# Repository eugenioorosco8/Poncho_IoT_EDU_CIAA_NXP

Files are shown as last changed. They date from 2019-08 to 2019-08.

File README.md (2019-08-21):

# Poncho_IoT_EDU_CIAA_NXP
El proyecto argentino CIAA, con alcance latinoamericano, lleva adelante el desarrollo y producción de sistemas embebidos, con fines educativos, industriales y científicos. El presente es un sistema embebido integral basado en la versión EDU-CIAA NXP, con fines educativos y de investigación aplicada. Se desarrolla el Hardware y el Software requeridos con el fin de proporcionar un circuito impreso de expansión de “Internet de las cosas” (IoT), capaz de brindar múltiples tecnologías como son: Wifi, Bluetooth, GSM, portabilidad SD, y RF. El desarrollo posee dos partes principales. La primera, basada en un microcontrolador ATMEL, consiste en la utilización de nodos provistos de sensores y módulos de comunicación. En la segunda parte, se diseña un nodo central de gran capacidad de procesamiento. La plataforma de desarrollo Nacional EDU-CIAA NXP, en conjunto con la placa de expansión IoT diseñada se emplea en la segunda etapa.

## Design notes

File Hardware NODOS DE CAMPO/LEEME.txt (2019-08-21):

En esta carpeta se encuentran los archivos de KiCAD del PCB del nodo.
En la carpeta componentes_nodo.pretty se encuentran los componentes electrronicos creados para el nodo, ya que se recomienda crear nosotros mismos los componentes que vamos a utilizar (creacion de librerias).
Las carpetas socket son plantillas que incluyen los terminales del arduino Nano. estas plantillas se pueden obtener desde GitHub, al igual que plantillas de otras plataformas.

NODO.sch--> Esquematico del diseño
NODO.pcb--> PCB del proyecto (pistas)
los demas archivos son empleados por los dos anteriores.

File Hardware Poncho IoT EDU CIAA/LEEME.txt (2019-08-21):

En este directorio se encuentran todos los archivos necesario para editar el poncho de la EDU CIAA
-->PCB para imprimir : se encuentran todos los archivos pdf para realizar el circuito PCB
-->lib : Se encuentran todos los mudulos creados , ordenados por Carpeta
-->basico.pcb :archivo KiCAD del circuito PCB
-->basico.sch : archivo KiCad con diagrama esquematico

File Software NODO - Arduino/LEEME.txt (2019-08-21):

Se adjunta el codigo arduino para el funcionamiento de los nodos. El nodo 1 y 2 tienen variantes entre si, las mismas se encuentras comentadas en el codigo arduino.
Se incluyen todas las librerias requeridas para el proyecto.

Julian Juan Manuel Mayo 2019

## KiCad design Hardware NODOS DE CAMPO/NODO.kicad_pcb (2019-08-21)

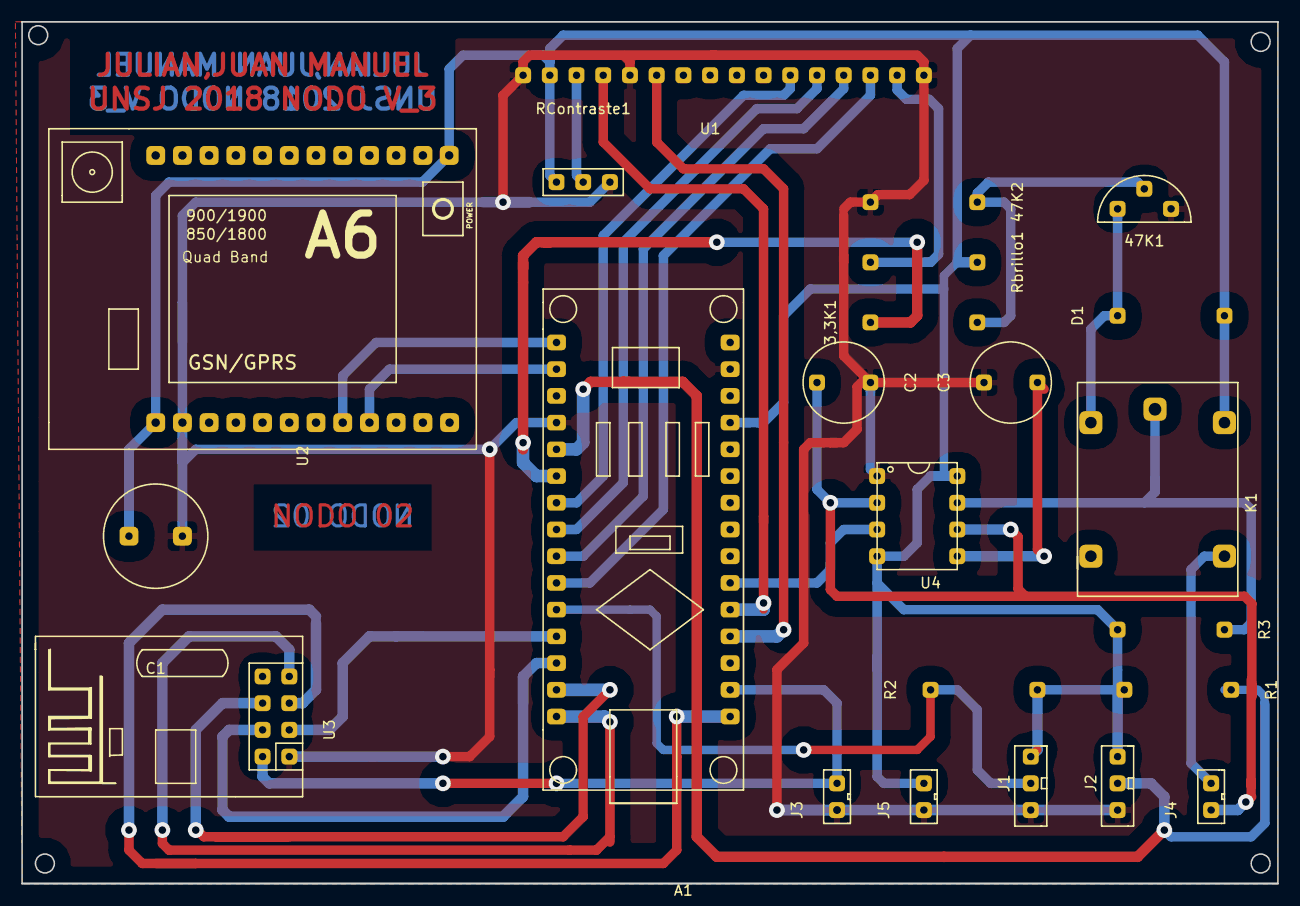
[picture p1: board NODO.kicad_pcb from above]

Board: 2 copper layers, 119.4 x 81.9 mm, 23 parts (0 on the bottom side), 28 nets.

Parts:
3,3K1: R1; Resistencia
47K1: BC337; Transisitor_BC337
47K2: R2; Resistencia
A1: Arduino_Nano_v3.x; Arduino_nano
C1: CP; Capacitor_GSM
C2: 0.1; capacitor
C3: CP; capacitor
D1: 1N4007; Resistencia
J1: Temp Suelo; connectorx3
J2: DHT22; connectorx3
J3: C 3.3V; connectorx2
J4: Sensor_HumedadS; connectorx2
J5: C 5V; connectorx2
K1: G5Q-1; rele
R1, R2: 10K; Resistencia
R3: 1K; Resistencia
RContraste1: 10K; potenciometro_presicion
Rbrillo1: R; Resistencia
U1: lcd_1602
U2: A6_GSM
U3: NRF24L01_Breakout; modulo_rf
U4: LM555

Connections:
/3.3V: A1.17, J3.1, U3.2
/5V: A1.27, C1.1, D1.1, J1.1, J2.1, J5.1, K1.5, R1.1, R2.1, R3.1, RContraste1.3, Rbrillo1.2, U1.2, U2.1, U2.24, U4.4, U4.8
/13(SCK): A1.16, U3.5
/+_SHUM: K1.2, R3.2, U4.7
/D2: A1.5, J2.2, R1.2
/D3: 3,3K1.2, A1.6
/D4: A1.7, U1.11
/D5: A1.8, U1.12
/D6: A1.9, U1.13
/D7: A1.10, U1.14
/D8: A1.11, J1.2, R2.2
/D9: A1.12, U3.3
/D10: A1.13, U3.4
/D11(MOSI): A1.14, U3.6
/D12(MISO): A1.15, U3.7
/POT_M: RContraste1.2, U1.3
/RX: A1.1, U2.8
/R_LIGHT: Rbrillo1.1, U1.15
/S_HUM+: J4.1, K1.3
/S_HUM-: C2.1, J4.2, U4.2, U4.6
/S_Hum: A1.21, U4.3
/TX: A1.2, U2.9
GND: 47K1.3, 47K2.1, A1.4, A1.29, C1.2, C2.2, C3.2, J1.3, J2.3, J3.2, J5.2, RContraste1.1, U1.1, U1.5, U1.16, U2.2, U3.1, U4.1
unnamed: 3,3K1.1, 47K1.2, 47K2.2
unnamed: 47K1.1, D1.2, K1.1
unnamed: A1.19, U1.6
unnamed: A1.20, U1.4
unnamed: C3.1, U4.5

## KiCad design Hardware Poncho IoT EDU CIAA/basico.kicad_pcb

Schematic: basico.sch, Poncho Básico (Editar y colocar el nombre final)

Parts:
C1: CP; CP_Radial_D10.0mm_P5.00mm
RV1: R_POT_US
U1: NRF24L01_Breakout; nRF24L01_Breakout
U2: ESP8266_CIAA
U3: HC05
U4: SD_card_CIAA
U5: A6_GSM; A6_gsm
U6: lcd_1602
XA101: Conn_Poncho2P_2x_20x2; Conn_Poncho_SinBorde; Digikey# 952-1387-ND

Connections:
+3.3VP: U1.2, XA101.41 (+3.3V)
+3V3: U2.6, XA101.1 (+3.3V)
+5V: C1.1, RV1.1, U3.5, U4.2, U5.1, U6.1, U6.15, XA101.2 (+5V), XA101.42 (+5V)
/CE: U1.3, XA101.78 (GPIO7)
/CS: U4.6, XA101.74 (GPIO3)
/CSN: U1.4, XA101.69 (GPIO0)
/D4: U6.11, XA101.70 (lcd1)
/D5: U6.12, XA101.68 (lcd2)
/D6: U6.13, XA101.66 (lcd3)
/D7: U6.14, XA101.62 (lcd4)
/E: U6.6, XA101.63 (lcdEN)
/IRQ: U1.8, XA101.76 (GPIO5)
/MISO: U1.7, U4.3, XA101.58 (spiMISO)
/MOSI: U1.6, U4.4, XA101.61 (spiMOSI)
/PWR_A6: U5.24, XA101.80 (GPIO8)
/RS: U6.4, XA101.64 (lcdRS)
/SCK: U1.5, U4.5, XA101.60 (spiSCK)
/UART0_RX: U5.8, XA101.71 (GPIO2)
/UART0_TX: U5.9, XA101.72 (GPIO1)
/UART2_RX: U3.3, XA101.50 (ethCRS)
/UART2_TX: U3.2, XA101.49 (ethRXD0)
/UART3_RX: U2.5, XA101.23 (rs232RXD)
/UART3_TX: U2.4, XA101.25 (rs232TXD)
GND: C1.2, RV1.3, U1.1, U2.1, U3.4, U4.1, U5.2, U5.23, U6.2, U6.5, U6.7, U6.8, U6.9, U6.10, U6.16, XA101.4 (GND), XA101.40 (GND), XA101.43 (GND)
unnamed: RV1.2, U6.3

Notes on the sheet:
UART0
UART2
UART3
WI-FI
BLUETOOTH
GPRS
SD_CARD
SPI

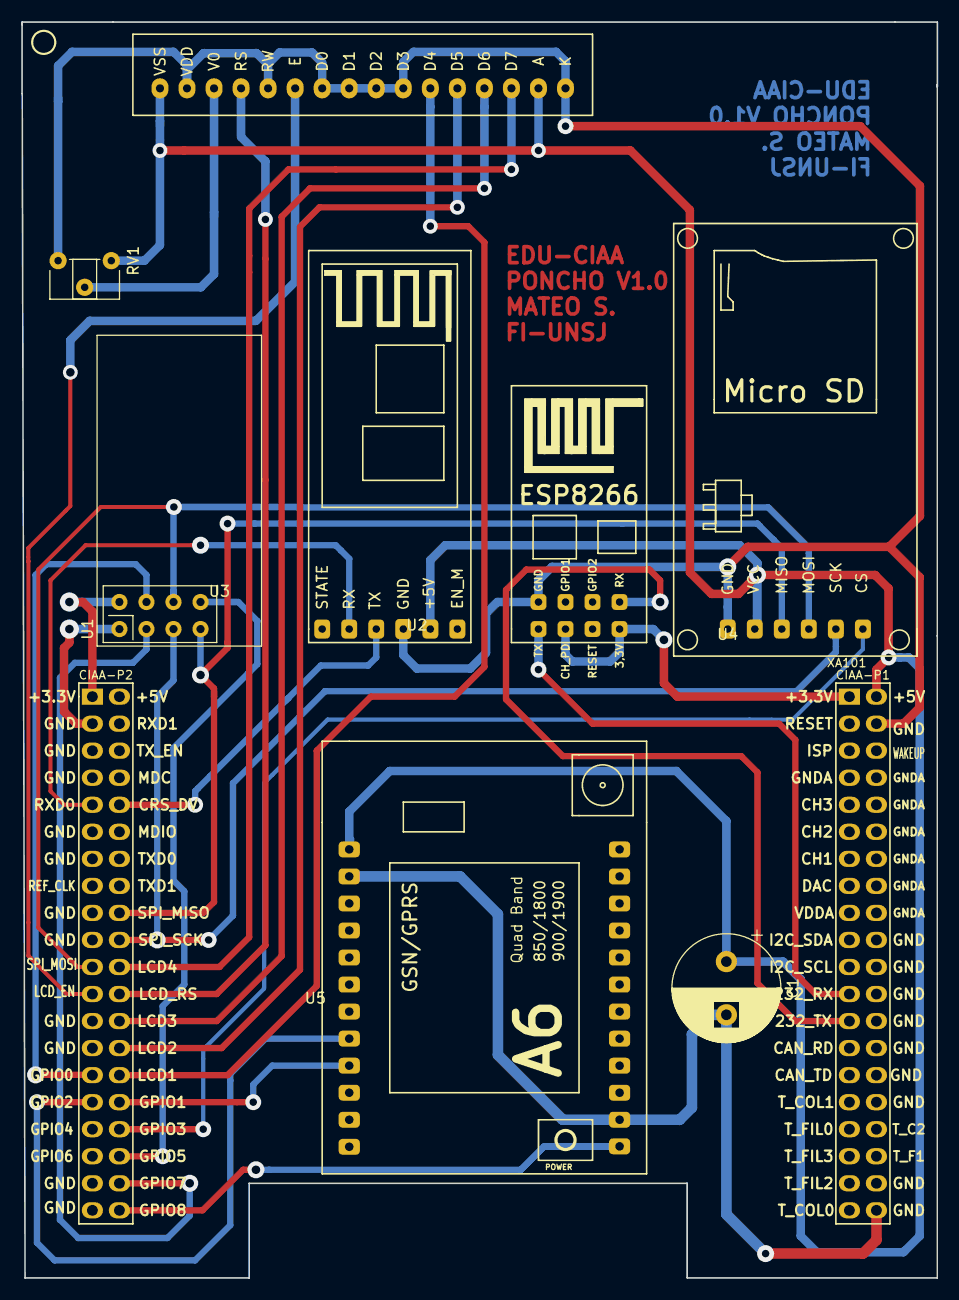
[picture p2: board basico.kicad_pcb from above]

Board: 2 copper layers, 86.0 x 118.0 mm, 9 parts (0 on the bottom side), 25 nets.

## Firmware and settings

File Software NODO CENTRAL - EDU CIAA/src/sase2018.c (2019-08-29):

/*
===============================================================================
 /*
===============================================================================
 Name        : test.c
 Author      :JULIAN BY MATEO
 Version     :
 Copyright   : $(copyright)
 Description : main definition
===============================================================================
*/

#if defined (__USE_LPCOPEN)
#if defined(NO_BOARD_LIB)
#include "chip.h"
#else
#include "board.h"
#endif
#endif

#include <cr_section_macros.h>
//---------------------- INCLUDES PROJECT SD-----------------------------

#include <chip.h>
#include "ff.h"
#include <diskio.h>
#include "WorkSD.h"
#include "rtc.h"
#include <string.h>
#include <stdlib.h>
#include "WorkApp.h"
// LCD
#include "puertos.h"
#include "lcd.h"
// ESP8266
#include "Serial.h"
#include "ESP8266.h"


//--------------------- ESP8266 ------------------------------------------
#define Intentos 2
#define Tiempo_Espera 7 // equivale a 14 seg
#define ssid "wifi-2"
#define password "tplinkmateo15"
unsigned char flag_WiFi=0, flag_GPRS=0, time_out=0, busy=0,pipe;

//**********************************************************************************************************
//                     Interrupcion del RIT Timer
//**********************************************************************************************************

 void RIT_IRQHandler(void){
	 uint16_t static contador=0;
	 if(contador < 15){ contador ++;}
	 else{ contador=0;  }

     time_out++;
     Chip_RIT_ClearInt(LPC_RITIMER);
     NVIC_ClearPendingIRQ(RITIMER_IRQn);
}



//---------------------INCLUDES PROJECT RF--------------------------------

	#include "UPC_nRF24L01.h"

	uint8_t pipe_00[5] = {"PIPE0"};
	uint8_t pipe_01[5] = {"PIPE1"};
    unsigned char mensaje[8] = {1,2,4,8,16,32,64,128};
    #define  nameWidth 3
	#define FCH 90
	#define dataRate 0 // 0-> 1Mbps  ,   1-> 2Mbps
	#define PowerOut 3 //0=> -18dBm, 1 => -12dBm, 2 => -6dBm, 3 => 0dBm
	#define EnableChecksum 0 // 0->Disable , 1 -> Enable
	#define PAYLOAD 8  // NUMEROS DE BYTES A ENVIAR
    #define LNA_Gain 1 //  0 => Disabled, 1 => Enabled
	#define CRC_Setup 2 //0 => 1byte, 1 => 2byte
    #define Mascara_Pipe 0b00001110


//-------------------------INCLUDE PROJECT BLUETOOTH--------------------------

#include  "Work_Bluetooth.h"

 //------------------------INCLUDE ADC TANQUE---------------------------------

#include "Work_ADC.h"

//------------------------------INCLUDE BOMBA--------------------------------

#include <Work_Bomba.h>

//---------------------------------INCLUDE CALENTADOR PID---------------------
#include "TriAc.h"
#define KI 0.03
#define KP 2
#define Tolerancia 2
#define Zona_Muerta 5
#define Ts 5

//-----------------------------VARIABLES GLOBALES------------------------------
    // Datos Pipe 0
    int Datos_SD[5]={0};	//Datos provenientes del Nodo 0
    char RX_Payload[8]={0};
    //Datos Pipe 1
    int Datos_SD_01 [5]={0};	//Datos provenientes del Nodo 1
    char RX_Payload_01[8]={0};

    int Ref_Temp_App=25;	//Dato de referencia primera pasada temperatura




//-------------------------INTERRUPT RIT----------------------------------------

  /*  void RIT_IRQHandler(void){
    static int Mediciones[4]={173,128,589,123}; //mediciones x10 (a una cifra decimal) samuel

    		/*Write_MeasurementsSD(Mediciones);
    		Last_Values_App(Mediciones);

    		Chip_RIT_ClearInt(LPC_RITIMER);
    		NVIC_ClearPendingIRQ(RITIMER_IRQn);


    }*/


//--------------------------------------MAIN------------------------------------

    //*************************************** lcd *********************************
    /*

*/

int main(void) {


#if defined (__USE_LPCOPEN)
    // Read clock settings and update SystemCoreClock variable

	SystemCoreClockUpdate();
#if !defined(NO_BOARD_LIB)
#if defined (__MULTICORE_MASTER) || defined (__MULTICORE_NONE)
    // Set up and initialize all required blocks and
    // functions related to the board hardware
    Board_Init();
#endif
    // Set the LED to the state of "On"
    Board_LED_Set(0, true);
#endif
#endif
// Force the counter to be placed into memory
volatile static int i = 0 ;
// Enter an infinite loop, just incrementing a counter

//******************************************* LCD  *********************************************************
    lcd_init_port();
    lcd_init();

    lcd_gotoxy(1, 1);
    printf_lcd("   TESIS 2019 ");
    lcd_gotoxy(1, 2);
    printf_lcd(" JULIAN - MATEO ");

//**************************************************************************
//**************** RITIMER**************************************************
//**************************************************************************
    /*
     Chip_RIT_Init(LPC_RITIMER);
     Chip_RIT_SetTimerInterval(LPC_RITIMER,2000);
     Chip_RIT_Enable(LPC_RITIMER);
     NVIC_EnableIRQ(RITIMER_IRQn);
*/
     uint8_t static caso=0,estado=0,cont_fail=0;

//***************************************************************************
//                  PIN POWER A6
//***************************************************************************
     Chip_SCU_PinMux (6,12,MD_PUP,FUNC3); // CS
     Chip_GPIO_SetPinDIROutput(LPC_GPIO_PORT,2, 8);
     Chip_GPIO_SetPinOutHigh(LPC_GPIO_PORT,2,8);

//----------------------------------------REGITRO HORARIO PARA SD ARCHIVOS--------------------------

  // int sec=0,min=34,hour=18,dayofmonth=11,dayofweek=16,dayofyear=190,month=12,year=2018 ;
   //rtc_set(sec,min,hour,dayofmonth,dayofweek,dayofyear,month,year); 	//Seteo valores iniciales del reloj
   rtc_init();

//----------------------------------------HABILITACION Y CONFIGURACION RIT-----------------------------

 /*  Chip_RIT_Init(LPC_RITIMER);
   Chip_RIT_SetTimerInterval(LPC_RITIMER,5000);
  Chip_RIT_Enable(LPC_RITIMER);
  NVIC_EnableIRQ(RITIMER_IRQn);*/


//---------------------------------------INIT HARDWARE SD------------------------------------------------

     initHardwareSD();

//------------------------------> INICIALIZA HARDWARE nRF24L01 RF RX<--------------------------------------
    Chip_SCU_PinMuxSet(0x6, 7, (SCU_MODE_PULLUP | SCU_MODE_FUNC4)); /* CS1 configured as GPIO0 */
   	Chip_GPIO_SetPinDIROutput(LPC_GPIO_PORT, 5, 15); //Chip Select en GPIO0
   	Chip_GPIO_SetPinOutHigh(LPC_GPIO_PORT,5,15);
    //MIRF_IRQinit();
    SPI_Start();
    nRF24L01_Ports_Start();
    Reset_nRF24L01_Status_and_nRF24L01_Payloads ();
    Start_RX_Mode_nRF24L01(nameWidth, FCH,dataRate, PowerOut,LNA_Gain, CRC_Setup,pipe_00,0x00,0x00, 0x00, 0x00, 0x00, EnableChecksum, 8, 8, 0, 0, 0, 0);

//-----------------------------------------INIT HARDWARE BLUETOOTH---------------------------------------


    Bluetooth_Init();

//-------------------------------------------INIT HARDWARE ADC----------------------------------------
  uint8_t channel_ADC_Tank=2;  	//Canal 2 para el ADC potenciometro tanque
  InicializarAdc(channel_ADC_Tank);

//---------------------------------------------INIT HARDWARE CALENTADOR-TRIAC---------------------------

  	////Triac_Init(3);
  	//PI_Init (KI,KP,Tolerancia,Zona_Muerta,Ts);







//*********************************************************************************************************
//             loop               loop               loop                  loop

//**********************************************************************************************************
    while(1) {


   if(dataReady() & busy==0){ //Si se recibe un dato via RF...


       lcd_gotoxy(1, 1);// limpia LCD
       printf_lcd("                ");
       lcd_gotoxy(1, 2);
       printf_lcd("                ");


      pipe= Read_nRF24L01_Status ();
      pipe= pipe & Mascara_Pipe;

     // si esta enviando un dato espera....

      if(pipe== 0b00000000){
    	   pipe=0;// Informacion Proveniente del Nodo 0
    	   busy=1; // Indica que el Nrf24l01, debe esperar hasta que el dato se envie al servidor
    	   flag_WiFi=1;// El dato sera enviado por Wifi

           lcd_gotoxy(1, 1); printf_lcd("Data Station 0  ");
           Receive_Data_RX_Mode_nRF24L01( 0,0, PAYLOAD,RX_Payload,Datos_SD);  //Dato recibido via RF desde Nodo en Datos_SD
           Reset_nRF24L01_Status_and_nRF24L01_Payloads ();// Limpia los Registros de Payload y Status
           Start_RX_Mode_nRF24L01(nameWidth, FCH,dataRate, PowerOut,LNA_Gain, CRC_Setup,0x00,pipe_01, 0x00, 0x00, 0x00, 0x00, EnableChecksum, 8, 8, 0, 0, 0, 0);
           Write_MeasurementsSD(Datos_SD,5, 0);// escribe Datos en La memoria SD, en el Archivo Correspondiente

      }
      if(pipe== 0b00000010){ // Verifica si el datos proviene del NODO 1
    	  pipe=1;// Informacion Proveniente del Nodo 1
    	  busy=1;// Indica que el Nrf24l01, debe esperar hasta que el dato se envie al servidor
    	  flag_WiFi=1;// El dato sera enviado por Wifi
          lcd_gotoxy(1, 1); printf_lcd("Data Station 1  ");
    	  Receive_Data_RX_Mode_nRF24L01( 0,0, PAYLOAD,RX_Payload_01,Datos_SD_01);  //Dato recibido via RF desde Nodo en Datos_SD
    	  Reset_nRF24L01_Status_and_nRF24L01_Payloads ();
    	  Start_RX_Mode_nRF24L01(nameWidth, FCH,dataRate, PowerOut,LNA_Gain, CRC_Setup,pipe_00,0x00, 0x00, 0x00, 0x00, 0x00, EnableChecksum, 8, 8, 0, 0, 0, 0);
    	  Write_MeasurementsSD(Datos_SD_01,5, 1);// Escribe Datos en La memoria SD, en el Archivo Correspondiente

      }


//--------------------------------Lectura de Nivel de tanque y asignacion-----------------------------------

      Datos_SD[4]=(int)((-0.1095)*AdcPolling())+100;	// Agrega litros de tanque
      Datos_SD[4]= 800;
      Datos_SD_01[4]= 800;

//--------------------------------Bucle de escritura en SD--------------------------------------------------

      //Write_MeasurementsSD(Datos_SD,5); 	//almacena paquete recibido via RF en archivo de SD
      Last_Values_App(Datos_SD);		//Almacena en arreglos historicos para graficar en  App

//-------------------------------Bucle de envio por Bluetooth-----------------------------------------------

      Bluetooth_GetData1(Datos_SD, 5);
      Bluetooth_GetData2(Datos_SD_01, 5);

 }// fin DATA Ready NRF24L01

////////////////////////////////////////////////////////////////////////////////////////////////////////////////////////////////
//                                          ENVIAR DATOS SERVIDOR                                                            //
///////////////////////////////////////////////////////////////////////////////////////////////////////////////////////////////

   	  if(flag_WiFi){

   	        switch(caso){
   	        	case 0:  // SE CONECTA RED WIFI
   	        		   Serial_Begin(115200);

   	        		   estado=ESP8266_begin(ssid,password);

   	        		   if(estado){
   	        			   caso=1; cont_fail =0;
   	        		   	   lcd_gotoxy(1, 1); printf_lcd("WiFi Conect     ");
   	        		   	   lcd_gotoxy(1, 2); printf_lcd("Connecting Cloud");
   	        		   }

   	        		   else {
   	        			   caso=0; cont_fail ++;
   	        			   lcd_gotoxy(1, 1);printf_lcd("WiFi Fail       ");
   	        		       lcd_gotoxy(1, 2);printf_lcd("Netword no found");
   	        		   }

   	        		   if(cont_fail > Intentos){
   	        			   flag_GPRS=1;   flag_WiFi=0; cont_fail =0; caso=0; busy=0;
   	        			   lcd_gotoxy(1, 1);printf_lcd("Connect A6 / GPRS");
   	        		       lcd_gotoxy(1, 2);printf_lcd("Company Claro AR");
   	        		   }

   	        	       break;

   	        	case 1: // SE CONECTA AL SERVIDOR THING SPEAK

   	        		 	estado=ESP266_ConnectThingSpeak();

   	        		 	if(estado){// CONEXION CON EXITO
   	        		 	 caso=2;cont_fail =0;flag_GPRS=0;
   	        		 	 lcd_gotoxy(1, 1); printf_lcd("Thing Speak     ");
   	        		 	 lcd_gotoxy(1, 2); printf_lcd("Connect......   ");
   	        		 	}

   	        		 	else{ caso=1; cont_fail++; }// FALLA EN CONEXION SERVIDOR

   	        		 	if(cont_fail > Intentos){
   	        		 		flag_GPRS=1;  flag_WiFi=0; cont_fail =0; caso=0; busy=0;
   	        		 	}

   	        	        break;

   	        	case 2:
   	        		 if(pipe==0){ estado=ESP8266_WriteChannel("CFDZGKH7ME80Z4FA",Datos_SD[0]/10,Datos_SD[1]/10,Datos_SD[2]/10,Datos_SD[3]/10,Datos_SD[4]/10);}

   	        		 if(pipe==1){estado=ESP8266_WriteChannel("EXNLVJJTBY17SM8V",Datos_SD_01[0]/10,Datos_SD_01[1]/10,Datos_SD_01[2]/10,Datos_SD_01[3]/10,Datos_SD_01[4]/10);}



   	        		    lcd_gotoxy(1, 1); printf_lcd("               ");
   	        		   	lcd_gotoxy(1, 2); printf_lcd("               ");
   	        		 	if(estado){
   	        		 		flag_WiFi=1;
   	        		 		caso=0;
   	        		 		busy=0;
   	        		 	    lcd_gotoxy(1, 1); printf_lcd("Uploadind Data  ");
   	        		 	    lcd_gotoxy(1, 2); printf_lcd("                ");
   	        		 	    delay();
   	        		 	} else{
   	       		 	        lcd_gotoxy(1, 1); printf_lcd("Fail Server     ");
   	    	        	    lcd_gotoxy(1, 2); printf_lcd("                ");
   	        		 		caso=0;
   	        		 		cont_fail++;
   	        		 		delay();
   	        		 	}

   	        		    if(cont_fail > Intentos){
   	        		    	flag_GPRS=1; flag_WiFi=0; cont_fail =0; caso=0; busy=0;
   	        		    }

   	        		    break;


   	        }

   	  }// fin flag_WIFi








}
  return 0;
}

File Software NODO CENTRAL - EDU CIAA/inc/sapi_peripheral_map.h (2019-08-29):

/* Copyright 2015, Eric Pernia.
 * Copyright 2016, Ian Olivieri.
 * Copyright 2016, Eric Pernia.
 * All rights reserved.
 *
 * This file is part sAPI library for microcontrollers.
 *
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
 * 3. Neither the name of the copyright holder nor the names of its
 *    contributors may be used to endorse or promote products derived from this
 *    software without specific prior written permission.
 *
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
 */

/* Date: 2015-09-23 */

#ifndef _SAPI_PERIPHERALMAP_H_
#define _SAPI_PERIPHERALMAP_H_

/*==================[inclusions]=============================================*/

#include "sapi_datatypes.h"

/*==================[cplusplus]==============================================*/

#ifdef __cplusplus
extern "C" {
#endif

/*==================[macros]=================================================*/

/*==================[typedef]================================================*/

/* ----- Begin Pin Config Structs NXP LPC4337 ----- */

typedef struct{
   int8_t port;
   int8_t pin;
} pinConfigLpc4337_t;

/* ------ End Pin Config Structs NXP LPC4337 ------ */


/* ------- Begin EDU-CIAA-NXP Peripheral Map ------ */

/* Defined for sapi_gpio.h */
typedef enum{
   /* EDU-CIAA-NXP */

   // P1 header
   T_FIL1,    T_COL2,    T_COL0,    T_FIL2,      T_FIL3,  T_FIL0,     T_COL1,
   CAN_TD,    CAN_RD,    RS232_TXD, RS232_RXD,

   // P2 header
   GPIO8,     GPIO7,     GPIO5,     GPIO3,       GPIO1,
   LCD1,      LCD2,      LCD3,      LCDRS,       LCD4,
   SPI_MISO,
   ENET_TXD1, ENET_TXD0, ENET_MDIO, ENET_CRS_DV, ENET_MDC, ENET_TXEN, ENET_RXD1,
   GPIO6,     GPIO4,     GPIO2,     GPIO0,
   LCDEN,
   SPI_MOSI,
   ENET_RXD0,

   // Switches
   // 36   37     38     39
   TEC1,  TEC2,  TEC3,  TEC4,

   // Leds
   // 40   41     42     43     44     45
   LEDR,  LEDG,  LEDB,  LED1,  LED2,  LED3,

   /* CIAA-NXP */
 /* 46     47     48     49     50     51     52     53 */
   DI0,   DI1,   DI2,   DI3,   DI4,   DI5,   DI6,   DI7,
 /* 54     55     56     57     58     59     60     61 */
   DO0,   DO1,   DO2,   DO3,   DO4,   DO5,   DO6,   DO7
} gpioMap_t;

/* Defined for sapi_adc.h */
typedef enum{
/* 62         63       64        65       */
   AI3 = 62, AI2 = 63, AI1 = 64, AI0 = 65,
             CH3 = 63, CH2 = 64, CH1 = 65
/*  46        47   48  49 */
// AI2 = 46, AI1, AI0, AO
} adcMap_t;

/* Defined for sapi_dac.h */
typedef enum{
/* 66 */
   AO = 66,
   DAC = 66
} dacMap_t;

/* Defined for sapi_uart.h */
typedef enum{
   UART_USB, UART_232, UART_485
} uartMap_t;

/*Defined for sapi_timer.h*/
//NOTE: if servo is enable (servoConfig used) the only available timer to use is TIMER0
typedef enum{
   TIMER0, TIMER1, TIMER2, TIMER3
} timerMap_t;
typedef enum{
   TIMERCOMPAREMATCH0, TIMERCOMPAREMATCH1, TIMERCOMPAREMATCH2, TIMERCOMPAREMATCH3
} timerCompareMatch_t;

/*Defined for sapi_sct.h*/
// NOTE: CTOUT11 has no SCT mode associated, so it can't be used!
// NOTE: if pwm is enable (pwmConfig used) there will be no sct channels available
typedef enum{
   CTOUT0, CTOUT1, CTOUT2, CTOUT3, CTOUT4, CTOUT5, CTOUT6, CTOUT7, CTOUT8,
   CTOUT9, CTOUT10, CTOUT11, CTOUT12, CTOUT13
} sctMap_t;

/*Defined for sapi_pwm.h*/
typedef enum{
   PWM0, PWM1, PWM2, PWM3, PWM4, PWM5, PWM6, PWM7, PWM8, PWM9, PWM10
} pwmMap_t;

/*Defined for sapi_servo.h*/
typedef enum{
   SERVO0, SERVO1, SERVO2, SERVO3, SERVO4, SERVO5, SERVO6, SERVO7, SERVO8
} servoMap_t;

/*Defined for sapi_i2c.h*/
/* Comment because already defined in "i2c_18xx_43xx.h"*/
/*
typedef enum{
   I2C0 // TODO: Add support for I2C1
} i2cMap_t;
*/
typedef uint8_t i2cMap_t;

typedef enum{
   SPI0
} spiMap_t;

/* ------- End EDU-CIAA-NXP Peripheral Map -------- */

/*==================[external data declaration]==============================*/

/*==================[external functions declaration]=========================*/

/*==================[cplusplus]==============================================*/

#ifdef __cplusplus
}
#endif

/*==================[end of file]============================================*/
#endif /* #ifndef _SAPI_PERIPHERALMAP_H_ */
